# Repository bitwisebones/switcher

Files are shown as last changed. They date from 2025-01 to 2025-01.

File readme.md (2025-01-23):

# Remote Switcher

A four channel MQTT-controlled button pusher.

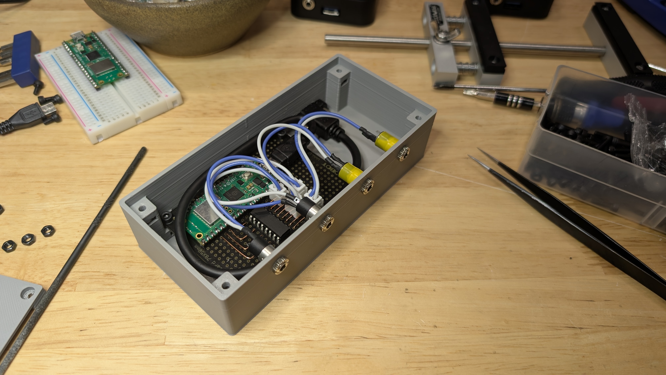
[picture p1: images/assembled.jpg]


## More Info

The accompanying blog post can be found [here](https://asciigraves.net/posts/workspace-2025-part-2/).

TL;DR - I have 2 KVMs and 2 USB switchers that can be controlled externally by buttons connected via 3.5mm audio cables. I want to be able to press those buttons remotely, and this does that for me.

## In this Repo
- Arduino code for the Pi Pico is in the `/code` folder
- FreeCAD project file, STLs, and gcode for an Ender 3 are in the `/cad` folder
- KiCad schematic is in the `/schematic` folder

## BOM
- 1 x Pi Pico W
- 4 x 3.5mm barrel connectors ([DigiKey Link](https://www.digikey.com/en/products/detail/lumberg-inc/1502-08/25602801))
- 1 x LTV-846 four channel optoisolator ([DigiKey Link](https://www.digikey.com/en/products/detail/liteon/LTV-846/385834))
- 1 x Panel-mount USB Micro cable ([DigiKey Link](https://www.digikey.com/en/products/detail/adafruit-industries-llc/3258/6238006))
- 1 x Perfboard ([DigiKey Link](https://www.digikey.com/en/products/detail/dfrobot/FIT0099/6588422))
- 1 x 3d printed enclosure (box and lid)
- 8 x M2 nuts
- 8 x M2 socket head bolts
- 4 x 2-pin JST connectors
- Misc wires, heat shink tubing

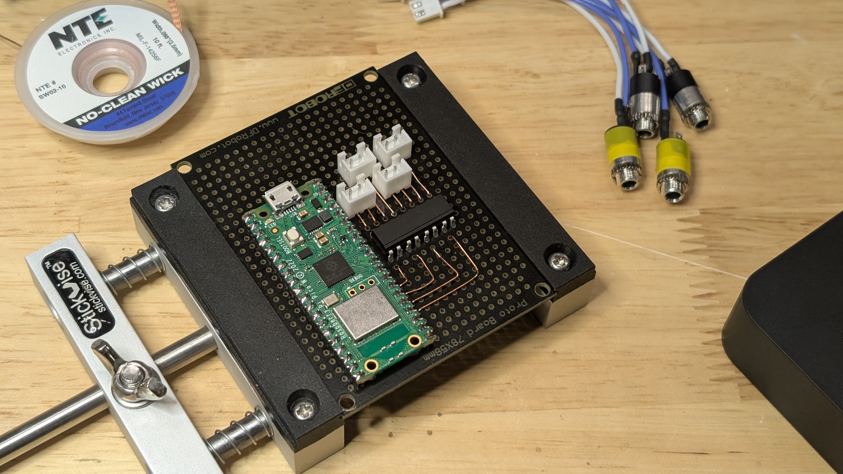
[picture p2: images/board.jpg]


# License

Code, schematics, images, and models are licensed under GPL v3 (see license file for details).

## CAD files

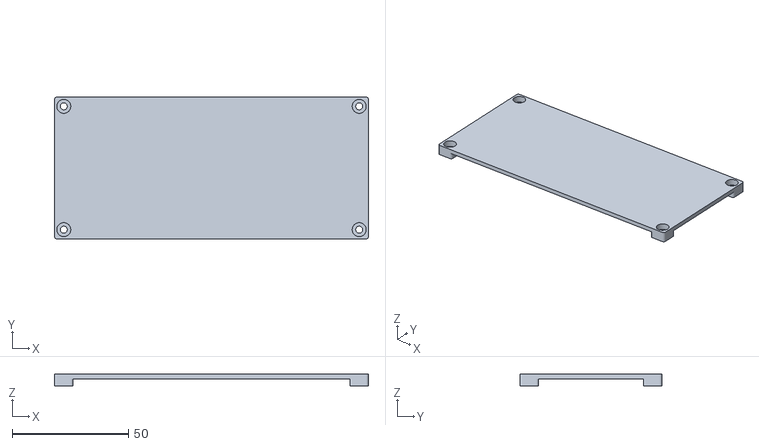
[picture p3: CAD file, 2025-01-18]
cad/enclosure-Enclosure Lid.stl
135.0 x 61.0 x 5.00

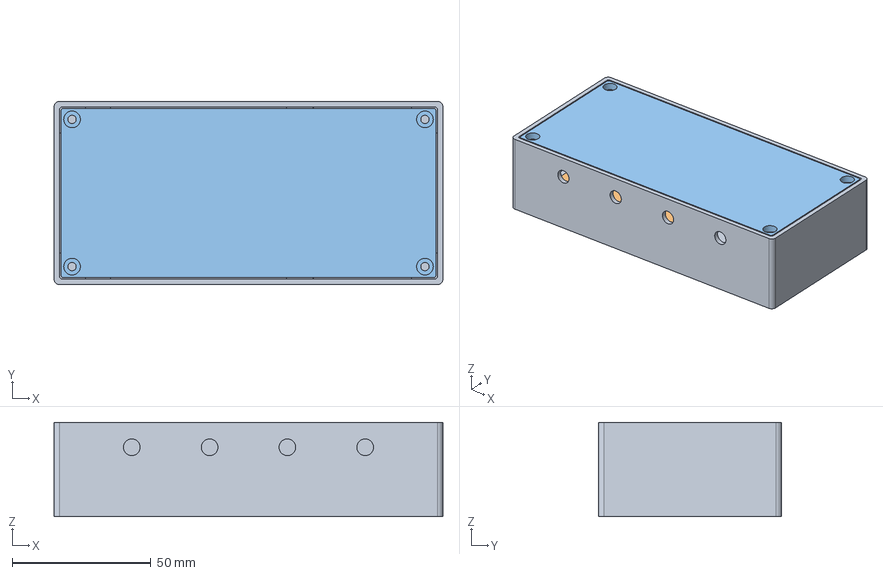
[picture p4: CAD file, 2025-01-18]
cad/enclosure.FCStd
140.0 x 66.0 x 34.0 mm
Perfboard

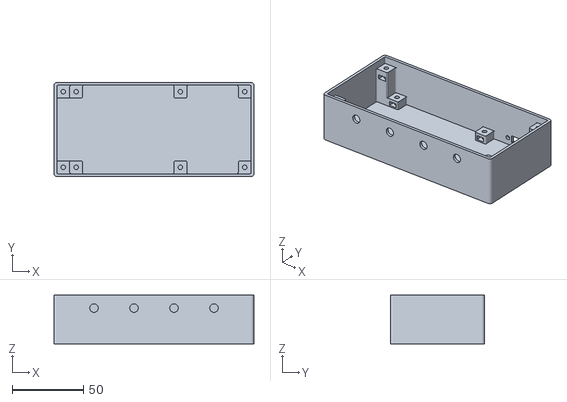
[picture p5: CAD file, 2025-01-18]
cad/enclosure-Enclosure Bottom.stl
140.0 x 66.0 x 34.0

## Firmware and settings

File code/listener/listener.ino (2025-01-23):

#include <ArduinoMqttClient.h>
#include <WiFi.h>
#include <math.h>

char ssid[] = "";
char pass[] = "";
int status = WL_IDLE_STATUS;

WiFiClient wifiClient;
MqttClient mqttClient(wifiClient);

const char broker[] = "";
int port = 1883;
const char topic[] = "";

// this ordering doesn't make much sense,
// it's just how I happened to plug in the 
// barrel connectors to the board
const int j1_pin = 20;
const int j2_pin = 21;
const int j3_pin = 19;
const int j4_pin = 18;

void setup() {
  pinMode(LED_BUILTIN, OUTPUT);
  pinMode(j1_pin, OUTPUT);
  pinMode(j2_pin, OUTPUT);
  pinMode(j3_pin, OUTPUT);
  pinMode(j4_pin, OUTPUT);
  
  Serial.begin(9600);
  while(!Serial) {}

  Serial.println("Attempting to connect to WiFi network...");

  while(WiFi.begin(ssid, pass) != WL_CONNECTED) {
    Serial.print(".");
    delay(1000);
  }

  Serial.println("Connected.");
  Serial.println("Attempting to connect to MQTT broker...");

  if(!mqttClient.connect(broker, port)) {
    Serial.print("MQTT connection failed. Error code = ");
    Serial.println(mqttClient.connectError());
    while(1);
  }

  Serial.println("Connected.");

  mqttClient.onMessage(onMqttMessage);

  Serial.print("Subscribing to topic: ");
  Serial.println(topic);
  mqttClient.subscribe(topic);
}

void loop() {
  mqttClient.poll();
  if(WiFi.status() != WL_CONNECTED) {
    Serial.print("WiFi Disconnected. Reconnecting");
    while(WiFi.begin(ssid, pass) != WL_CONNECTED) {
      Serial.print(".");
      delay(1000);
    }
  }
}

void onMqttMessage(int messageSize) {
  Serial.println("Received message.");

  if(messageSize > 2) {
    return;
  }

  digitalWrite(LED_BUILTIN, HIGH);

  static char message[2]; // buffer needs to be big enough for 1 char plus null terminator
  mqttClient.readBytes(message, messageSize);
  Serial.println(message);

  digitalWrite(LED_BUILTIN, LOW);

  if(message[0] == '1') {
    digitalWrite(j1_pin, HIGH);
    delay(100);
    digitalWrite(j1_pin, LOW);
  }
  if(message[0] == '2') {
    digitalWrite(j2_pin, HIGH);
    delay(100);
    digitalWrite(j2_pin, LOW);
  }
  if(message[0] == '3') {
    digitalWrite(j3_pin, HIGH);
    delay(100);
    digitalWrite(j3_pin, LOW);
  }
  if(message[0] == '4') {
    digitalWrite(j4_pin, HIGH);
    delay(100);
    digitalWrite(j4_pin, LOW);
  }

  message[0] = 0;
  message[1] = 0;
}

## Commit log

2025-01-15 initial schematic
    [remote-switcher.kicad_sch]
2025-01-18 finalized code, schematic, and enclosure
    [enclosure-Enclosure Bottom.stl, enclosure-Enclosure Lid.stl, enclosure.FCStd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]
2025-01-22 micropython wifi is garbage, switch to arduino
